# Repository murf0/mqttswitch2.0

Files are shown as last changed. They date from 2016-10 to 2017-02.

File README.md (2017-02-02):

**mqttSwitch2.0**
==========
**Features:**

ESP8266
* Status of GPIO pins as published mqtt-message
* Capability of esp sent on boot to mqtt broker
* Set status of GPIO pin (on-off for now) via MQtt Message (Set at compiletime capabilities)
* WifiManager with Mqtt settings available
* OTA prepared (For boards with more than 4mbit memory)
* Mangled version of [MQTT library for the ESP8266 ](https://github.com/tuanpmt/esp_mqtt) library included. Will now work with Arduino ESP8266 SDK. (after a slight mod to platform.txt)
* Mqtt with SSL enabled only
* Mqtt with username + password

HTML
* Java-script enabled interface to control multiple switches. Uses Getvariables for username/password
* Nice-name for each switch configured here
* No webserver required everything is handled in web-browser

OTA Firmwarecheck
* php required, script included based on the standard examples.

**Installation**
(Instructions for macOS)

* edit: ~/Library/Arduino15/packages/esp8266/hardware/esp8266/2.3.0 platform.txt  add "-lssl --allow-multiple-definition" to the end of the Linker row. (the row begins with compiler.c.elf.libs=)
See http://www.delorie.com/gnu/docs/binutils/ld_3.html for information. The linker uses the first found definition)
* symlink in Mqtt library "ln -s $(pwd)/lib/mqtt ~/Documents/Arduino/libraries/mqtt" or move it there
***Libraries used***
* [MQTT library for the ESP8266 ](https://github.com/tuanpmt/esp_mqtt) By Tuanpmt (thanks!) (This is included in the repo for use by Arduino ESP8266) (MIT-License)
* [WifiManager library for the ESP8266 ](https://github.com/tzapu/WiFiManager#install-through-library-manager) By Tzapu (MIT-License)
* [ArduinoJson library for Arduino](https://github.com/bblanchon/ArduinoJson) (MIT-License)

**Hardware**
(This description is a mess sorry, please see included eagle files)
GPIO2 is connected to the base of a NPN3906 transistor via a 1k resistor. Collector is conneted to Ground, Emittor is connected to the Relay. the Groound of relay to 5.0v (USB)
ESP8266 -03, GPIO 15 via 10k resistor to ground, CH_PD via 10k resistor to VCC 3.3v regulator AMS1117 connected to VCC5.0

***Schematic***
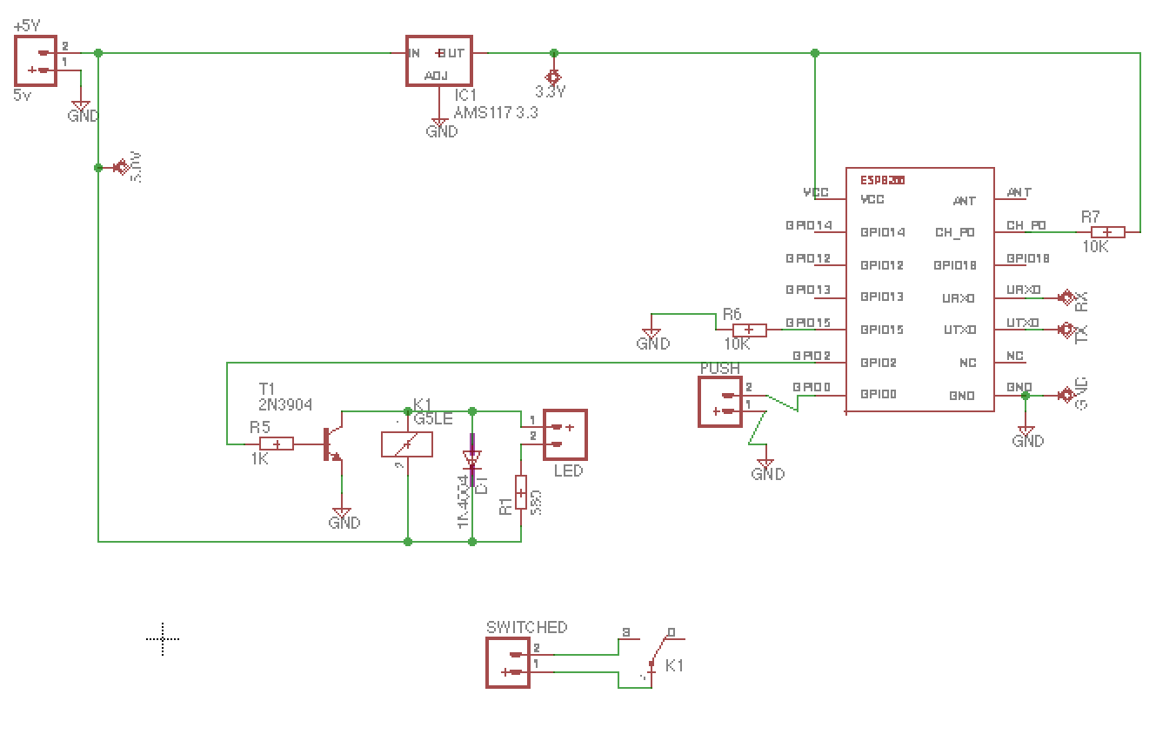
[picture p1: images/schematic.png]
Schematic


***Board***
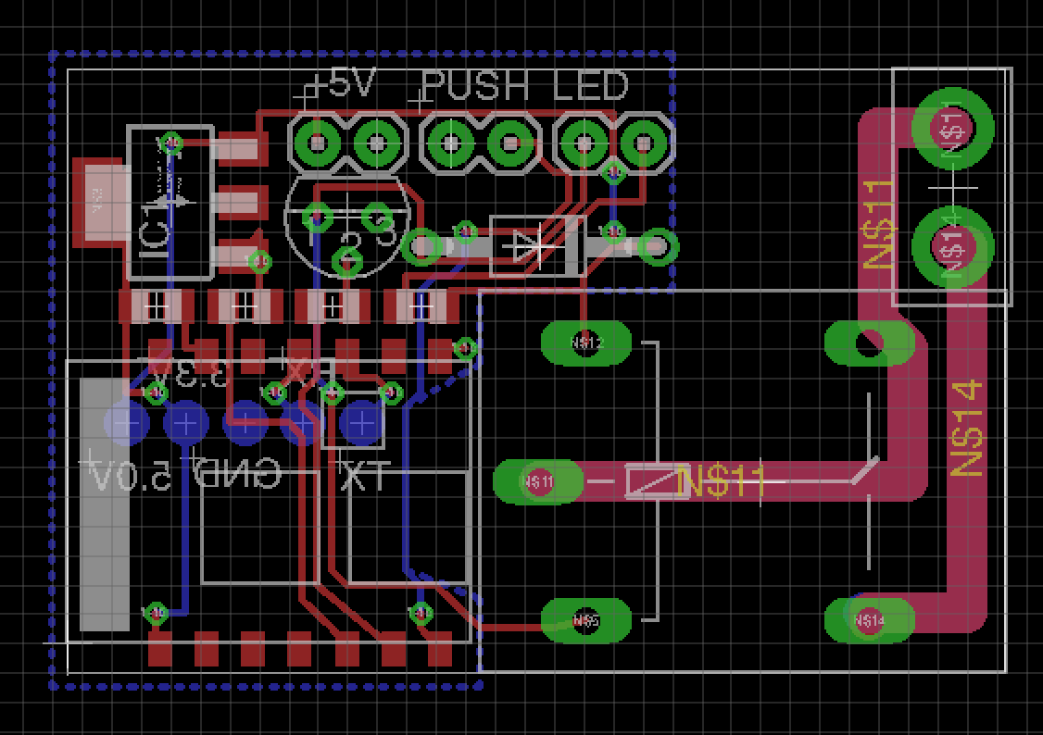
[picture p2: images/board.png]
Board Schematic


**Author:**
[Mikael "Murf" Mellgren](https://murf.se)

**LICENSE - "BSD"**
mqttSwitch2.0: Copyright (c) 2017 Mikael MURF Mellgren , https://murf.se

Redistribution and use in source and binary forms, with or without modification, are permitted provided that the following conditions are met:

1. Redistributions of source code must retain the above copyright notice, this list of conditions and the following disclaimer.

2. Redistributions in binary form must reproduce the above copyright notice, this list of conditions and the following disclaimer in the documentation and/or other materials provided with the distribution.

THIS SOFTWARE IS PROVIDED BY THE COPYRIGHT HOLDERS AND CONTRIBUTORS "AS IS" AND ANY EXPRESS OR IMPLIED WARRANTIES, INCLUDING, BUT NOT LIMITED TO, THE IMPLIED WARRANTIES OF MERCHANTABILITY AND FITNESS FOR A PARTICULAR PURPOSE ARE DISCLAIMED. IN NO EVENT SHALL THE COPYRIGHT HOLDER OR CONTRIBUTORS BE LIABLE FOR ANY DIRECT, INDIRECT, INCIDENTAL, SPECIAL, EXEMPLARY, OR CONSEQUENTIAL DAMAGES (INCLUDING, BUT NOT LIMITED TO, PROCUREMENT OF SUBSTITUTE GOODS OR SERVICES; LOSS OF USE, DATA, OR PROFITS; OR BUSINESS INTERRUPTION) HOWEVER CAUSED AND ON ANY THEORY OF LIABILITY, WHETHER IN CONTRACT, STRICT LIABILITY, OR TORT (INCLUDING NEGLIGENCE OR OTHERWISE) ARISING IN ANY WAY OUT OF THE USE OF THIS SOFTWARE, EVEN IF ADVISED OF THE POSSIBILITY OF SUCH DAMAGE.

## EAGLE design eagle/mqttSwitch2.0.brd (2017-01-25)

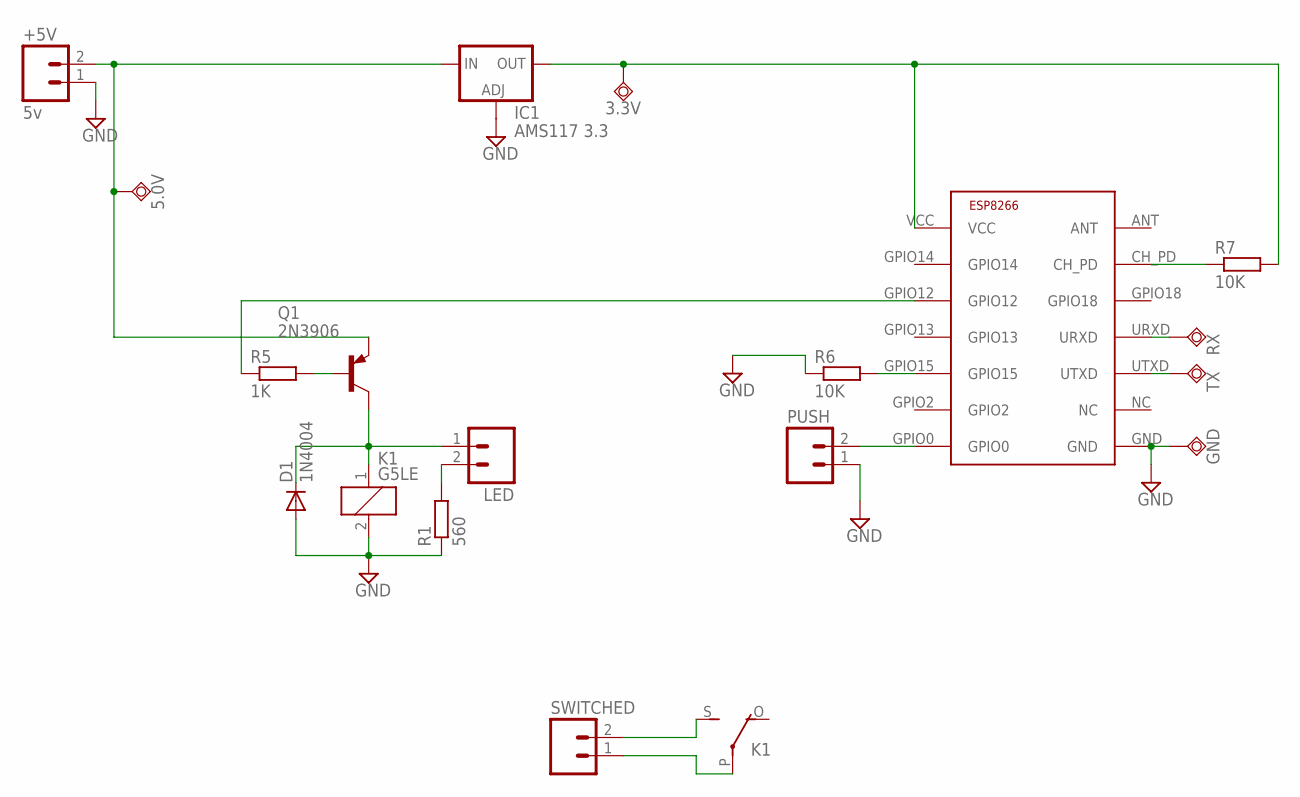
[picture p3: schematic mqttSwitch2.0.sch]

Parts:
3.3V, 5.0V: TPSQTP19R; TP19R
+5V: 5v; 1X02
D1: 1N4004; DO41-10
GND: TPSQTP19R; TP19R
IC1: AMS117 3.3; SOT223
K1: G5LE
LED: M02PTH; 1X02
PUSH: M02PTH; 1X02
Q1: 2N3906; TO92
R1: 560; R0805
R5: 1K; R0805
R6, R7: 10K; R0805
RX: TPSQTP19R; TP19R
SWITCHED: M02PTH4; 1X02_XTRA_BIG
TX: TPSQTP19R; TP19R
U$1: ESP8266; ESP-03

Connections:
GND: +5V.1, D1.A, GND.TP, IC1.1 (ADJ), K1.2, PUSH.1, R1.1, R6.1, U$1.GND
unnamed: RX.TP, U$1.URXD
unnamed: R7.1, U$1.CH_PD
unnamed: 3.3V.TP, IC1.4 (OUT), R7.2, U$1.VCC
unnamed: 5.0V.TP, +5V.2, IC1.3 (IN), Q1.3 (E)
unnamed: Q1.2 (B), R5.2
unnamed: R6.2, U$1.GPIO15
unnamed: D1.C, K1.1, LED.1, Q1.1 (C)
unnamed: TX.TP, U$1.UTXD
unnamed: PUSH.2, U$1.GPIO0
unnamed: K1.P, SWITCHED.1
unnamed: LED.2, R1.2
unnamed: R5.1, U$1.GPIO12
unnamed: K1.S, SWITCHED.2

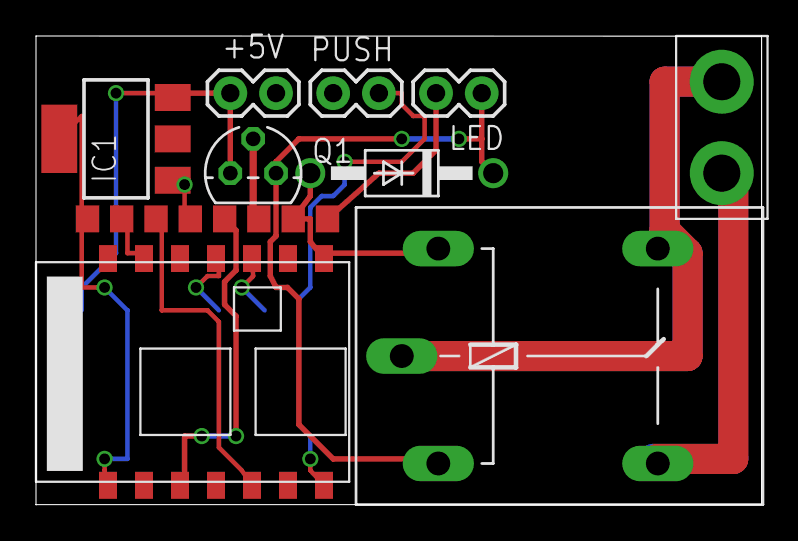
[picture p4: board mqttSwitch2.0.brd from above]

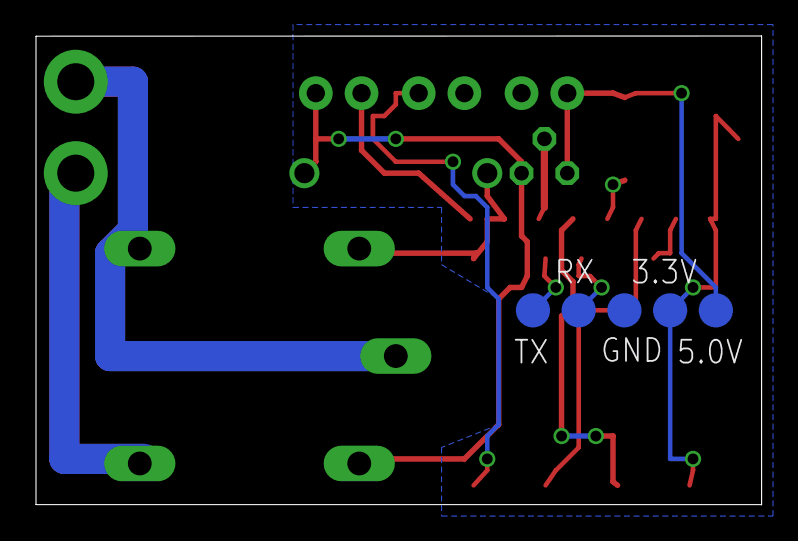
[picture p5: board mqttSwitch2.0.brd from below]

Board: 2 copper layers, 40.3 x 26.0 mm, 18 parts (5 on the bottom side), 14 nets.

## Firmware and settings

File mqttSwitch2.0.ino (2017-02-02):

#include <FS.h>                   //this needs to be first, or it all crashes and burns...
#include <ESP8266WiFi.h>
#include <ESP8266mDNS.h>

#include <ESP8266WiFiMulti.h>
#include <ESP8266HTTPClient.h>
#include <ESP8266httpUpdate.h>
#include <Ticker.h>

/*
   FIX The SDK
   edit: ~/Library/Arduino15/packages/esp8266/hardware/esp8266/2.3.0/platform.txt  add "-lssl --allow-multiple-definition" to the end of the Linker row. (the row begins with compiler.c.elf.libs)
   See http://www.delorie.com/gnu/docs/binutils/ld_3.html for information. (The linker uses the first found definition)
   If you get issues First try and remove the -laxtls and build only with legacy ssl.
   symlink in Mqtt library "ln -s $(pwd)/lib/mqtt ~/Documents/Arduino/libraries/mqtt" or move it there

*/

//flag for saving data
bool shouldSaveConfig = false;

//Settings
//External connection which GPIO is connected
const int external_btn = 0;
const int external_relay = 2;

//Define OTA Settings
#define BUILD_TAG 0.0.2
#define CHECK_INTERVAL 60
String checkUrl = "http://192.168.0.156/esp/firmware.php";

//Global Variables
#define TEXTIFY(A) #A
#define ESCAPEQUOTE(A) TEXTIFY(A)
String buildTag = ESCAPEQUOTE(BUILD_TAG);


ESP8266WiFiMulti WiFiMulti;
Ticker updateCheck;
boolean doUpdateCheck = true;

void setup_gpio() {
#ifdef NPN
  pinMode(external_relay, INPUT);
#else
   pinMode(external_relay, OUTPUT);
  digitalWrite(external_relay, LOW);
#endif
  pinMode(external_btn, INPUT_PULLUP);
}


/*
 * Setup function, Here we initialize Wifimanager, Gpios, MQTT connections and finally set up the OTA check
 */
void setup() {
  Serial.begin(115200);
  Serial.println();
  setup_wifi();
  setup_gpio();
  init_mqtt();
  updateCheck.attach(CHECK_INTERVAL, updateCheckCB);

  Serial.print("ESP: Free sketchspace: ");
  Serial.println(ESP.getFreeSketchSpace());
}

void loop() {
  //See ota.ino for OTA functions.
  updateCheckDo();
  //Nothing More to do here... 
}

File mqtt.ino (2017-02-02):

#include <ArduinoJson.h>          //https://github.com/bblanchon/ArduinoJson
#include <WiFiManager.h>          //https://github.com/tzapu/WiFiManager
#include <c_types.h>
#include <os_type.h>
#include <mem.h>

extern "C" {
#include "ets_sys.h"
#include "os_type.h"
#include "osapi.h"
#include "mem.h"
#include "user_interface.h"
#include "cont.h"
#include "eagle_soc.h"
#include "espconn.h"
void *pvPortZalloc(size_t, char * file, int line);
} 

typedef boolean BOOL;
#include <mqtt.h>

typedef struct{
    uint8_t mqtt_host[64];
    uint32_t mqtt_port;
    uint8_t mqtt_user[32];
    uint8_t mqtt_pass[32];
    uint8_t client_id[16];
    uint32_t mqtt_keepalive;
    uint8_t security;
} MQTTCFG;

MQTTCFG mqttcfg;

char subtopic[64];
char statustopic[64];
char registertopic[64];
int GPIO2_status = 0;
int GPIO13_status = 0;

MQTT_Client mqttClient;
int RESET=0;
volatile long LASTRESETTIME=0;

/*Set up debug messages*/
#define dbg 1


/*#define CAPABILITY "{\"%s\":{\"Adress\":\"%s\",\"Capability\":{\"GPIO02\": \"true\",\"GPIO13\": \"true\"}}}"*/
#define CAPABILITY "{\"%s\":{\"Adress\":\"%s\",\"Capability\":{\"GPIO02\": \"true\"}}}"

// Button Press debouncing
// Holds the last time debounce was evaluated (in millis).
volatile long lastDebounceTime = 0;
// The delay threshold for debounce checking.
const int debounceDelay = 500;

void btnPressed() {
  //Serial.println("BTN: btnPressed (Before Debounce check)");
  //Do Debouncing
  boolean debounce = false;
  // Check to see if the change is within a debounce delay threshold.
  if((millis() - lastDebounceTime) <= debounceDelay) {
    debounce = true;
  }
  lastDebounceTime = millis();
  if(debounce) {
    return; 
  }
  if((millis() - LASTRESETTIME) <= 10000) {
    RESET++;
  } else {
    RESET=0;
  }
  LASTRESETTIME = millis();
  
  //USING PNP 2N3906
  char temp[128];
  //Serial.println("BTN: btnPressed");
  DynamicJsonBuffer jsonBuffer2;
  JsonObject& jsonmsgresponse = jsonBuffer2.createObject();
  JsonObject& data = jsonmsgresponse.createNestedObject((const char*)mqttcfg.client_id);
    if(digitalRead(external_relay) == LOW) {
      pinMode(external_relay, INPUT);
      data["GPIO02"] = "OFF";
    } else {
      pinMode(external_relay, OUTPUT);
      digitalWrite(external_relay,LOW);
      data["GPIO02"] = "ON";
    }
  jsonmsgresponse.printTo(temp,sizeof(temp));
  MQTT_Publish(&mqttClient, statustopic, temp, os_strlen(temp), 2, 0);
  Serial.println(RESET);
  if( RESET > 9) {
      WiFiManager wifiManager;
      wifiManager.resetSettings();
      ESP.restart();
  }
}

void mqttConnectedCb(uint32_t *args) {
    Serial.print("MQTT: mqttConnectedCb");
    MQTT_Client* client = (MQTT_Client*)args;
    char temp[128];
    char offline[128];
    DynamicJsonBuffer jsonBuffer;
    JsonObject& jsonmsgresponse = jsonBuffer.createObject();
    JsonObject& data = jsonmsgresponse.createNestedObject((const char*)mqttcfg.client_id);   
     
    os_sprintf(subtopic,"iot/switch/%s/set",mqttcfg.client_id);
    os_sprintf(statustopic,"iot/switch/%s/status",mqttcfg.client_id);
    os_sprintf(temp,CAPABILITY, mqttcfg.client_id,subtopic);
    
    data["Adress"] = subtopic;
    data["Capability"] = "OFFLINE";
    jsonmsgresponse.printTo(offline, sizeof(offline));
    //jsonmsgresponse.printTo(Serial);
    
    //MQTT_InitLWT(MQTT_Client *mqttClient, uint8_t* will_topic, uint8_t* will_msg, uint8_t will_qos, uint8_t will_retain);
    MQTT_InitLWT(client, (uint8_t*) statustopic, (uint8_t*) offline, (uint8_t) 2, (uint8_t)1);
    MQTT_Subscribe(client, subtopic, 2);
    Serial.print("MQTT: subscribed to ");
    Serial.println(subtopic);
    Serial.print("MQTT: Statustopic is ");
    Serial.println(statustopic);
    Serial.print("MQTT: Capability ");
    Serial.println(temp);
    Serial.print("MQTT: LWT payload ");
    Serial.println(offline);
    MQTT_Publish(client, statustopic, temp, os_strlen(temp), 2, 1);
}


void mqttDisconnectedCb(uint32_t *args) {
  Serial.print("MQTT: mqttDisconnectedCb");
  MQTT_Client* client = (MQTT_Client*)args;
  Serial.println("MQTT: Disconnected");
  //ESP.restart();
}

void mqttPublishedCb(uint32_t *args) {
  Serial.print("MQTT: mqttPublishedCb");
  MQTT_Client* client = (MQTT_Client*)args;
  Serial.println("MQTT: Published");
}

void mqttDataCb(uint32_t *args, const char* topic, uint32_t topic_len, const char *data, uint32_t data_len) {
   Serial.print("MQTT: mqttDataCb");
   char *topicBuf = (char*)os_zalloc(topic_len+1), *dataBuf = (char*)os_zalloc(data_len+1);
  
   MQTT_Client* client = (MQTT_Client*)args;
   int i;
   bool sendmsg=false;
   char *tmp_gpios, *status, *out;
   char temp[128];
    
   os_memcpy(topicBuf, topic, topic_len);
    topicBuf[topic_len] = 0;
    os_memcpy(dataBuf, data, data_len);
    dataBuf[data_len] = 0;

    Serial.print("MQTT: Received on topic: ");
    Serial.println(topicBuf);
    Serial.print("MQTT: Data:");
    Serial.println(dataBuf);
    /*PARSE MESSG
    Commands available is: 
    {\"GPIO02\":\"ON\"}
    {\"GPIO02\":\"OFF\"}
    {\"GPIO02\":\"STATUS\"}
    */
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

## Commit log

2016-10-26 First commit, Working
    [mqttSwitch2.0.brd, mqttSwitch2.0.sch]
2017-01-25 Updated to NPN, Started on KiCad
    [mqttSwitch2.0.brd, mqttSwitch2.0.kicad_pcb, mqttSwitch2.0.sch]
2017-01-26 Removed NPN nonsense, Does not work USE PNP 2n3906
    [mqttSwitch2.0.sch]

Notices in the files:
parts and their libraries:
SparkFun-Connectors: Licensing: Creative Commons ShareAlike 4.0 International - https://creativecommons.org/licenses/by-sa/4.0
